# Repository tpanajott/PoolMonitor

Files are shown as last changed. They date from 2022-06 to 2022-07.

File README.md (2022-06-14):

# PoolMonitor

<!-- @import "[TOC]" {cmd="toc" depthFrom=1 depthTo=6 orderedList=false} -->

<!-- code_chunk_output -->

- [PoolMonitor](#poolmonitor)
  - [Description](#description)
  - [Hardware](#hardware)
    - [PCB Manufacturing](#pcb-manufacturing)
    - [Parts](#parts)
    - [Sensor](#sensor)
    - [Jumpers](#jumpers)
      - [Disable pol prot](#disable-pol-prot)
      - [Disable power ctrl](#disable-power-ctrl)
  - [Installation of software](#installation-of-software)
  - [Home Assistant configuration](#home-assistant-configuration)

<!-- /code_chunk_output -->

## Description
This is a small PCB made to monitor the temperature of a pool using a DS18B20 waterproof sensor. The PCB is based around a ESP-12 module that will connect to WiFi periodically (period time configurable) and report the temperature together with battery voltage via MQTT. In between the meassurements, the sensors are turned off to save battery.

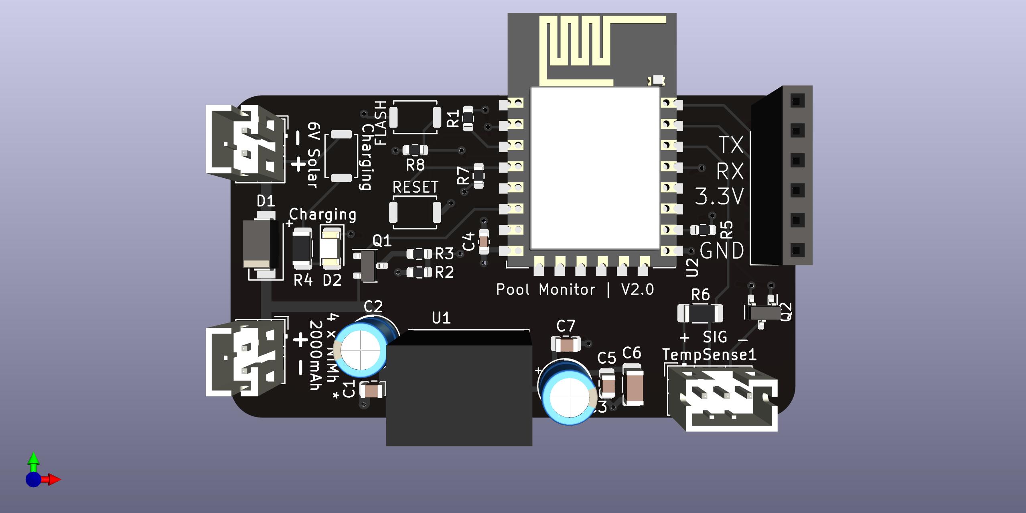
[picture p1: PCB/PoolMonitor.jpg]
PCB Preview


## Hardware
### PCB Manufacturing
I had the board manufactured at [JLCPCB](https://jlcpcb.com/). Simply upload the ZIP-file in the `PCB/gerbers` directory to their website. The following PCB stackup is used:
|Layer|Name|
|---|---|
|L1(Top Layer)|PoolMonitor-F_Cu.gtl|
|L2(Inner Layer1)|PoolMonitor-GND.g2|
|L3(Inner Layer2)|PoolMonitor-3_3V.g3|
|L4(Bottom Layer)|PoolMonitor-B_Cu.gbl|

### Parts
A BOM for the project is available in the file `PCB/PoolMonitor.csv`. The parts list have references to [LCSC](https://lcsc.com/) part numbers.

### Sensor
This board is designed to use a simple DS18B20 sensor with three wires. The following wiring diagram is to be used and the sensor should be connected to the `TempSense1` connector.
|Wire Color|Connection|
|---|---|
|Red|+|
|Black|-|
|Yellow|D|

### Jumpers
#### Disable pol prot
This jumber, when briged, will disable the polarity protection on the power input.
#### Disable power ctrl
This jumber will, when briged, disable to power control of the DS18B20 sensor when not reading from it. By default the power to the DS18B20 sensor will only be turned on while reading data from it in an attempt to conserve power.

## Installation of software
1. Connect a FTDI programmer set to 3.3V to the header on the PCB.
2. Download and installation VS Code together with the PlatformIO extention.
3. Download this repo and open it with PlatformIO.
4. Hold the SW_FLASH1 button and press and release the SW_RESET1 button. This will put the device into a programming mode.
5. Create a copy of the "settings.h.example" file found in the "src/" directory and name it `settings.h`.
6. Configure all relevant paramaters in the `settings.h` file.
7. Make sure to save everything and then press "Upload" in PlatformIO.
8. Once the upload is complete, disconnect the FTDI-programmer.
9. Done, enjoy.

## Home Assistant configuration
The following configuration example can be added to the `sensor` section in your Home Assistant configuration. The `expire_after` paramater set to 4200 means that Home Assistant will consider the value old if 70 minutes has passed since last update from sensor. This value may need to be changed in order to reflect your configuration of the `SLEEP_TIME` paramater in the `settings.h` file.
```yaml
- platform: mqtt
  device_class: temperature
  name: "Pool temperature"
  state_topic: "/pool/temp/"
  unit_of_measurement: "°C"
  expire_after: 4200
- platform: mqtt
  device_class: temperature
  name: "Pool sensor voltage"
  state_topic: "/pool/voltage/"
  unit_of_measurement: "V"
  expire_after: 4200
```

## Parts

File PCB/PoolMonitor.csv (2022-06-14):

Comment | Designator | Footprint | LCSC
10uF | C1,C5 | Capacitor_SMD:C_0805_2012Metric | C440198
22uF | C2,C3 | Capacitor_THT:CP_Radial_D5.0mm_P2.00mm | C89789
1uf | C4 | Capacitor_SMD:C_0603_1608Metric | C92828
4.7uF | C6 | Capacitor_SMD:C_1206_3216Metric | C132170
100nF | C7 | Capacitor_SMD:C_0805_2012Metric | C49678
SW_Push | CHK_CHARGE1,SW_FLASH1,SW_RESET1 | Button_Switch_SMD:SW_Push_SPST_NO_Alps_SKRK | C115357
SS14 | D1 | Diode_SMD:D_SMA | C2837270
LED_GREEN | D2 | LED_SMD:LED_1206_3216Metric | C125085
Conn_01x02_Male | J1 | Connector_JST:JST_PH_B2B-PH-K_1x02_P2.00mm_Vertical | C131337
Conn_01x06_Female | J2 | Connector_PinSocket_2.54mm:PinSocket_1x06_P2.54mm_Vertical | C225503
SolarPanel6V | J3 | Connector_JST:JST_PH_B2B-PH-K_1x02_P2.00mm_Vertical | C131337
DMP2225L-7 | Q1 | Package_TO_SOT_SMD:SOT-23 | C110501
AO3400A | Q2 | Package_TO_SOT_SMD:SOT-23 | C344010
10K | R1,R3,R7,R8 | Resistor_SMD:R_0603_1608Metric | C98220
2K | R2 | Resistor_SMD:R_0603_1608Metric | C22975
1K | R4 | Resistor_SMD:R_1206_3216Metric
10k | R5 | Resistor_SMD:R_0603_1608Metric | C98220
4k7 | R6 | Resistor_SMD:R_1206_3216Metric_Pad1.30x1.75mm_HandSolder | C242482
Conn_01x03_Male | TempSense1 | Connector_JST:JST_PH_B3B-PH-K_1x03_P2.00mm_Vertical | C131339
K7803M-1000R3 | U1 | CustomFootprints:CONV_K7803M-1000R3 | C494983
ESP-12E | U2 | RF_Module:ESP-12E | C89297

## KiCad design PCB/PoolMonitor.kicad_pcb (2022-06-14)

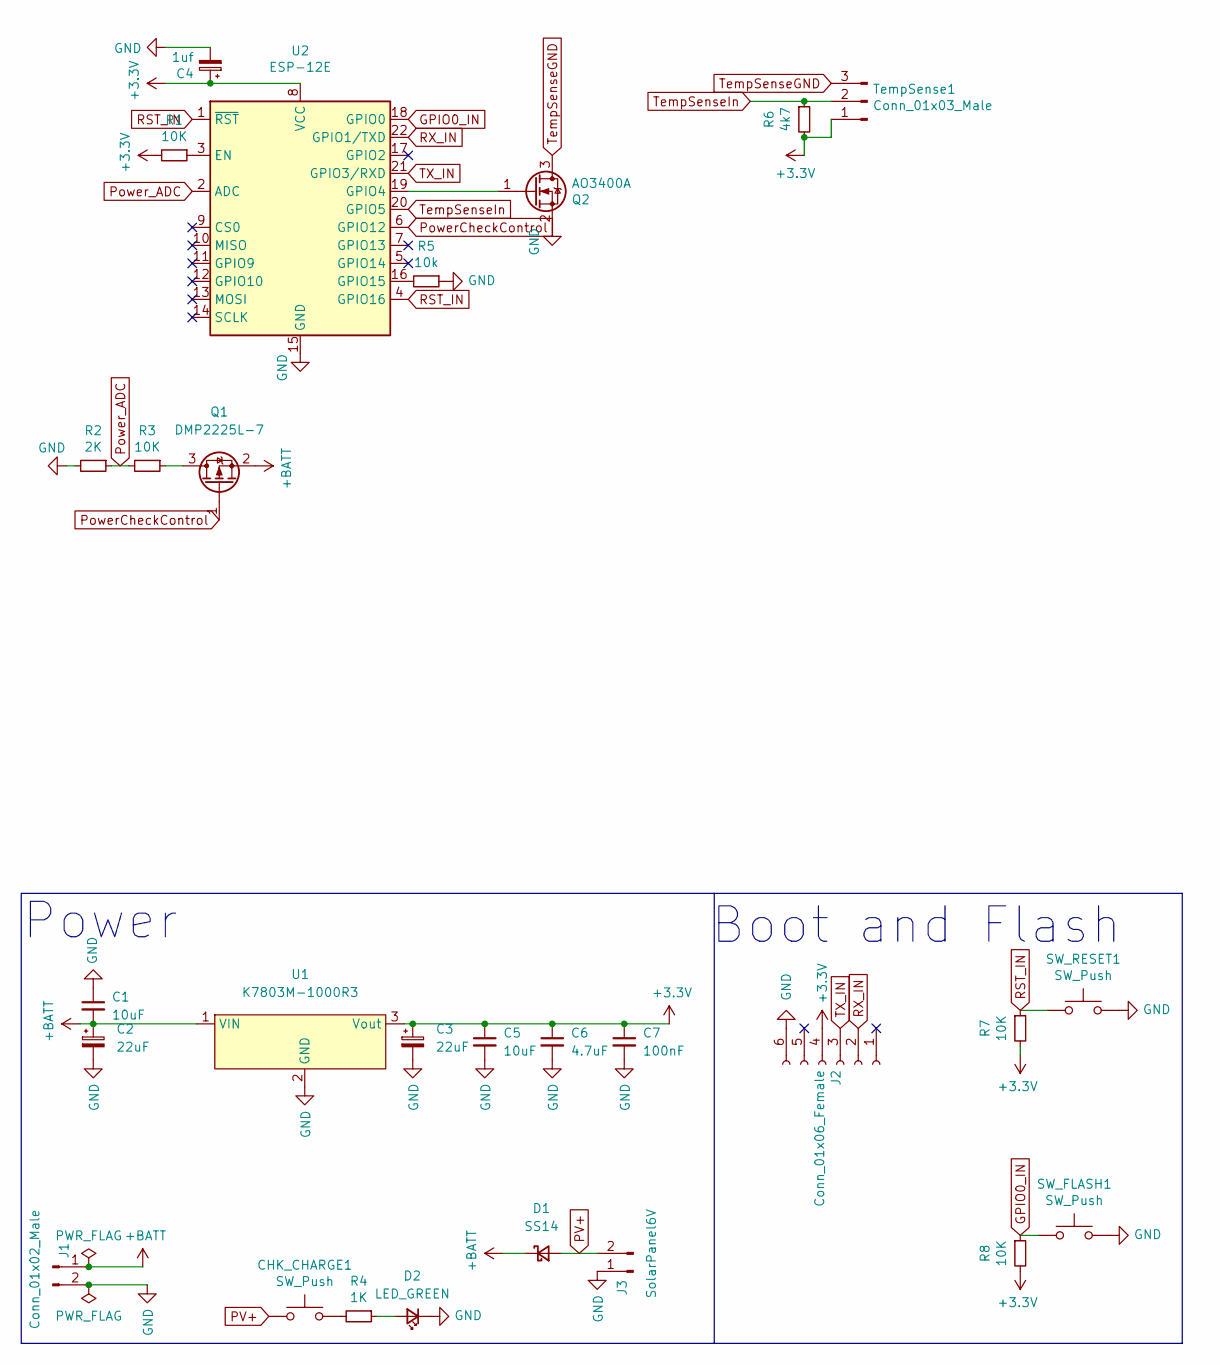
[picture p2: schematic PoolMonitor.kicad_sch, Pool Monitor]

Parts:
C1, C5: 10uF; C_0805_2012Metric; LCSC C440198
C2, C3: 22uF; CP_Radial_D5.0mm_P2.00mm; LCSC C89789
C4: 1uf; C_0603_1608Metric; LCSC C92828
C6: 4.7uF; C_1206_3216Metric; LCSC C132170
C7: 100nF; C_0805_2012Metric; LCSC C49678
CHK_CHARGE1: SW_Push; SW_Push_SPST_NO_Alps_SKRK; LCSC C115357
D1: SS14; D_SMA; LCSC C2837270
D2: LED_GREEN; LED_1206_3216Metric; LCSC C125085
J1: Conn_01x02_Male; JST_PH_B2B-PH-K_1x02_P2.00mm_Vertical; LCSC C131337
J2: Conn_01x06_Female; PinSocket_1x06_P2.54mm_Vertical; LCSC C225503
J3: SolarPanel6V; JST_PH_B2B-PH-K_1x02_P2.00mm_Vertical; LCSC C131337
Q1: DMP2225L-7; SOT-23; LCSC C110501
Q2: AO3400A; SOT-23; LCSC C344010
R1, R3, R7, R8: 10K; R_0603_1608Metric; LCSC C98220
R2: 2K; R_0603_1608Metric; LCSC C22975
R4: 1K; R_1206_3216Metric
R5: 10k; R_0603_1608Metric; LCSC C98220
R6: 4k7; R_1206_3216Metric_Pad1.30x1.75mm_HandSolder; LCSC C242482
SW_FLASH1: SW_Push; SW_Push_SPST_NO_Alps_SKRK; LCSC C115357
SW_RESET1: SW_Push; SW_Push_SPST_NO_Alps_SKRK; LCSC C115357
TempSense1: Conn_01x03_Male; JST_PH_B3B-PH-K_1x03_P2.00mm_Vertical; LCSC C131339
U1: K7803M-1000R3; CONV_K7803M-1000R3; LCSC C494983
U2: ESP-12E; LCSC C89297

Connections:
+3V3: C3.1, C4.1, C5.1, C6.1, C7.1, J2.4, R1.2, R6.2, R7.2, R8.2, TempSense1.1, U1.3 (Vout), U2.8 (VCC)
+BATT: C1.2, C2.1, D1.1 (K), J1.1, Q1.2 (S), U1.1 (VIN)
GND: C1.1, C2.2, C3.2, C4.2, C5.2, C6.2, C7.2, D2.1 (K), J1.2, J2.6, J3.1, Q2.2 (S), R2.2, R5.1, SW_FLASH1.2, SW_RESET1.2, U1.2 (GND), U2.15 (GND)
GPIO0_IN: R8.1, SW_FLASH1.1, U2.18 (GPIO0)
unnamed: CHK_CHARGE1.2, R4.2
unnamed: D2.2 (A), R4.1
unnamed: Q1.3 (D), R3.1
unnamed: Q2.1 (G), U2.19 (GPIO4)
unnamed: R1.1, U2.3 (EN)
unnamed: R5.2, U2.16 (GPIO15)
PV+: CHK_CHARGE1.1, D1.2 (A), J3.2
PowerCheckControl: Q1.1 (G), U2.6 (GPIO12)
Power_ADC: R2.1, R3.2, U2.2 (ADC)
RST_IN: R7.1, SW_RESET1.1, U2.1 (~RST), U2.4 (GPIO16)
RX_IN: J2.2, U2.22 (GPIO1/TXD)
TX_IN: J2.3, U2.21 (GPIO3/RXD)
TempSenseGND: Q2.3 (D), TempSense1.3
TempSenseIn: R6.1, TempSense1.2, U2.20 (GPIO5)

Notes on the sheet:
Power
Boot and Flash

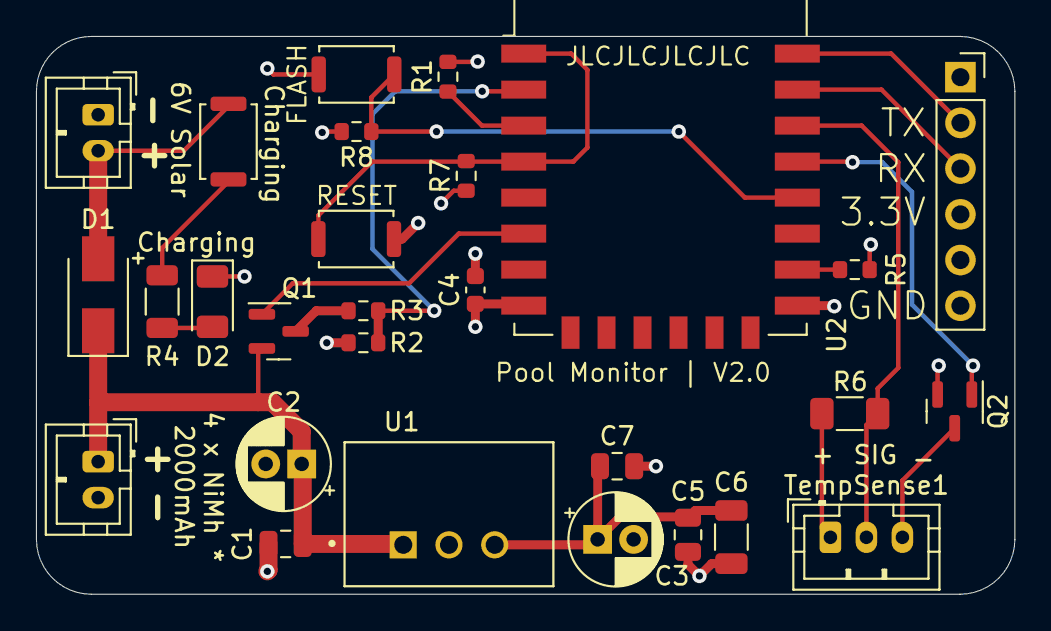
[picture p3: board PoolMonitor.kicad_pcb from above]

Board: 4 copper layers, 54.4 x 31.0 mm, 28 parts (0 on the bottom side), 18 nets.

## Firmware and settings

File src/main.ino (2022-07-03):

/*************************************************
      Based on: https://arduinodiy.wordpress.com/2020/01/23/very-deep-sleep-part-3-mqtt/
 *************************************************/
//long SLEEPTIME = 600e6; //10min
//unsigned long SLEEPTIME = 3600L * 1000000L; // 1 hour
#include "Arduino.h"
#include <ESP8266WiFi.h>
#include "PubSubClient.h"
#include <settings.h>

// We make a structure to store connection information
// The ESP8266 RTC memory is arranged into blocks of 4 bytes. The access methods read and write 4 bytes at a time,
// so the RTC data structure should be padded to a 4-byte multiple.
struct {
  uint32_t crc32;   // 4 bytes
  uint8_t channel;  // 1 byte,   5 in total
  uint8_t ap_mac[6];// 6 bytes, 11 in total
  uint8_t padding;  // 1 byte,  12 in total
} rtcData;


// IPAddress ip(192, 168, 1, 7); // pick your own IP outside the DHCP range of your router
// IPAddress gateway(192, 168, 1, 1); //watch out, these are comma's not dots
IPAddress ip(IP_ADDRESS); // pick your own IP outside the DHCP range of your router
IPAddress subnet(IP_SUBNET);
IPAddress gateway(IP_GATEWAY); //watch out, these are comma's not dots
IPAddress dns(IP_DNS);
//--------- MQTT
WiFiClient espClient;
PubSubClient client(espClient);
//-------DS18B20-------
#include <OneWire.h>
#include <DallasTemperature.h>
OneWire oneWire(D1);
DallasTemperature temp_sensor(&oneWire);
float current_temperature = 0;
float current_voltage = 0;

void setup() {
  // Disable WiFi, coming from DeepSleep, as we do not need it right away
  WiFi.mode( WIFI_OFF );
  WiFi.forceSleepBegin();
  delay(1);
  
  // Set pin modes
  pinMode(DS18B20_FET_PIN, OUTPUT);
  pinMode(POWER_READ_PIN, INPUT); // Set ADC to INPUT
  pinMode(POWER_READ_CONTROL_PIN, OUTPUT); // Power flow control pin
  // Turn everything OFF as a default
  digitalWrite(DS18B20_FET_PIN, LOW);
  digitalWrite(POWER_READ_CONTROL_PIN, LOW);
  delay(50);

  // Get temperature while WiFi is off
  temp_sensor.begin();
  temp_sensor.setWaitForConversion(true); // Synchronious mode

  current_temperature = getCurrentTemperature();
  current_voltage = getPowerVoltage();

  // Try to read WiFi settings from RTC memory
  bool rtcValid = false;
  if ( ESP.rtcUserMemoryRead( 0, (uint32_t*)&rtcData, sizeof( rtcData ) ) ) {
    // Calculate the CRC of what we just read from RTC memory, but skip the first 4 bytes as that's the checksum itself.
    uint32_t crc = calculateCRC32( ((uint8_t*)&rtcData) + 4, sizeof( rtcData ) - 4 );
    if ( crc == rtcData.crc32 ) {
      rtcValid = true;
    }
  }
  

  // Start connection WiFi
  //Switch Radio back On
  WiFi.forceSleepWake();
  delay( 1 );

  // Disable the WiFi persistence.  The ESP8266 will not load and save WiFi settings unnecessarily in the flash memory.
  WiFi.persistent( false );
  // Bring up the WiFi connection
  WiFi.mode( WIFI_STA );
  WiFi.config( ip, dns, gateway, subnet );
  //-----------Now we replace the normally used "WiFi.begin();" with a precedure using connection data stored by us
  if ( rtcValid ) {
    // The RTC data was good, make a quick connection
    WiFi.begin( WLAN_SSID, WLAN_PASSWD, rtcData.channel, rtcData.ap_mac, true );
  }
  else {
    // The RTC data was not valid, so make a regular connection
    WiFi.begin( WLAN_SSID, WLAN_PASSWD );
  }
  //WiFi.begin( WLAN_SSID, WLAN_PASSWD );

  //------now wait for connection
  int retries = 0;
  int wifiStatus = WiFi.status();
  while ( wifiStatus != WL_CONNECTED ) {
    retries++;
    if ( retries == 100 ) {
      // Quick connect is not working, reset WiFi and try regular connection
      WiFi.disconnect();
      delay( 10 );
      WiFi.forceSleepBegin();
      delay( 10 );
      WiFi.forceSleepWake();
      delay( 10 );
      WiFi.begin( WLAN_SSID, WLAN_PASSWD );
    }
    if ( retries == 600 ) {
      // Giving up after 30 seconds and going back to sleep
      WiFi.disconnect( true );
      delay( 1 );
      WiFi.mode( WIFI_OFF );
      ESP.deepSleep(SLEEP_TIME, WAKE_RF_DISABLED );
      return; // Not expecting this to be called, the previous call will never return.
    }
    delay( 50 );
    wifiStatus = WiFi.status();
  }

  //-----
  // Write current connection info back to RTC
  rtcData.channel = WiFi.channel();
  memcpy( rtcData.ap_mac, WiFi.BSSID(), 6 ); // Copy 6 bytes of BSSID (AP's MAC address)
  rtcData.crc32 = calculateCRC32( ((uint8_t*)&rtcData) + 4, sizeof( rtcData ) - 4 );
  ESP.rtcUserMemoryWrite( 0, (uint32_t*)&rtcData, sizeof( rtcData ) );


  //---------As we are connected to WiFi, begin MQTT connection
  client.setServer(MQTT_SERV_IP, MQTT_PORT); //your MQTT server's IP.Mind you, these are separated by dots again
  //client.setCallback(callback);
  
  //-------Here is where you send data
  sendMQTTmessage();
  //------------------
  
  /* Close WiFi connection */
  //client.stop();

  //----and go to back to sleep
  WiFi.disconnect( true );
  delay( 1 );

  // WAKE_RF_DISABLED to keep the WiFi radio disabled when we wake up
  ESP.deepSleep(SLEEP_TIME, WAKE_RF_DISABLED );
}


void loop() {
  // Loop is never used. All magic is happening in setup, after setup is done the device will go to sleep
}

float getCurrentTemperature() {
  // Try to reset DS18B20-sensor and do another search if not found. Max 10 attempts
  for(int i = 0; i < 10 && temp_sensor.getDeviceCount() == 0; i++) {
    // Power cycle DS18B20 sensor
    digitalWrite(DS18B20_FET_PIN, LOW);
    delay(500);
    digitalWrite(DS18B20_FET_PIN, HIGH);
    delay(500);
    temp_sensor.begin();
  }

  float temp;
  // Try to get temperature. Max 10 attempts
  for(int i = 0; i < 10 && temp_sensor.getDeviceCount() > 0; i++) {
    temp_sensor.requestTemperatures();
    temp = temp_sensor.getTempCByIndex(0);

    // If the temperature that was retrieved was below -100 (not reasonable) then try again
    // else break. The default temperature when it fails to retreive a temperature is -127
    if(temp > -100) {
      break;
    } else {
      delay(500);
    }
  }
  // Turn off power to the DS18B20 sensor when the reading is done
  digitalWrite(DS18B20_FET_PIN, LOW);
  return temp;
}

float getPowerVoltage() {
  digitalWrite(POWER_READ_CONTROL_PIN, LOW); // Write LOW to enable flow of electricity.
  delay(10);
  float voltage = analogRead(A0);
  // Calculate actual voltage from ADC value
  // 1024 = 1V.
  // Resistor divider on PCB: 10K -> ADC -> 2K -> GND. This results in 6V = 1V on ADC.
  // 6V / 1024 = 
  voltage = voltage * 0.005859375;
  // Compensate for reading to high
  voltage = voltage * 0.913633160937;
  // Round voltage to 2 digits
  voltage = round(voltage * 100) / 100;
  
  digitalWrite(POWER_READ_CONTROL_PIN, HIGH); // Write HIGH to disable flow of electricity.
  delay(50);
  pinMode(POWER_READ_PIN, OUTPUT); // Set ADC to input to block current flow
  return voltage;
}

void sendMQTTmessage()
{
  if (!client.connected()) {
    reconnect();
  }
  char current_temp[10];
  char current_volt[10];
  itoa(current_temperature, current_temp, 10);
  itoa(current_voltage, current_volt, 10);

  client.publish(MQTT_TEMP_TOPIC, current_temp, false);
  client.publish(MQTT_VOLT_TOPIC, current_volt, false);
  delay(10);
  
  /* Close MQTT client cleanly */
  client.disconnect();
}

void reconnect() {
  int failed_counter = 0;
  while (!client.connected())
  {
    bool connectSuccessful = false;
    if(MQTT_USE_AUTH) {
      connectSuccessful = client.connect(MQTT_DEVICE_NAME, MQTT_USERNAME, MQTT_PASSWORD);
    } else {
      connectSuccessful = client.connect(MQTT_DEVICE_NAME);
    }

    if (!connectSuccessful)
    {
      Serial.print("failed, rc= ");
      Serial.print(client.state());
      delay(1000);
      failed_counter++;
      if(failed_counter >= 3) {
        // 3 or more failed attempts to connect to MQTT server was made. Stop trying and go back to sleep
          WiFi.disconnect( true );
          delay( 1 );

          // WAKE_RF_DISABLED to keep the WiFi radio disabled when we wake up
          ESP.deepSleep(3600*1e6, WAKE_RF_DISABLED );
      }
    }
  }
}

// the CRC routine
uint32_t calculateCRC32( const uint8_t *data, size_t length ) {
  uint32_t crc = 0xffffffff;
  while ( length-- ) {
    uint8_t c = *data++;
    for ( uint32_t i = 0x80; i > 0; i >>= 1 ) {
      bool bit = crc & 0x80000000;
      if ( c & i ) {
        bit = !bit;
      }

      crc <<= 1;
      if ( bit ) {
        crc ^= 0x04c11db7;
      }
    }
  }

  return crc;
}

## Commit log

2022-01-17 First commit of PCB and code
    [PoolMonitor.csv, PoolMonitor.kicad_pcb, PoolMonitor.kicad_sch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]
2022-06-14 Updated PCB and software to be able to read battery voltage as well as added solar charging capabilities to PCB
    [PoolMonitor.csv, PoolMonitor.kicad_pcb]
2022-06-14 Updated to use all JST connectors and updated REAME with a description
    [PoolMonitor.csv, PoolMonitor.kicad_pcb, PoolMonitor.kicad_sch]
2022-06-14 Removed designators as they were not needed
    [PoolMonitor.kicad_pcb]
2022-06-24 Added workaround for errenious readings every once in a while. If a readins is below -100C, try again up to three times
    [main.ino]
2022-07-03 Implemented fix for sometimes not getting a reading from the sensor
    [main.ino]
